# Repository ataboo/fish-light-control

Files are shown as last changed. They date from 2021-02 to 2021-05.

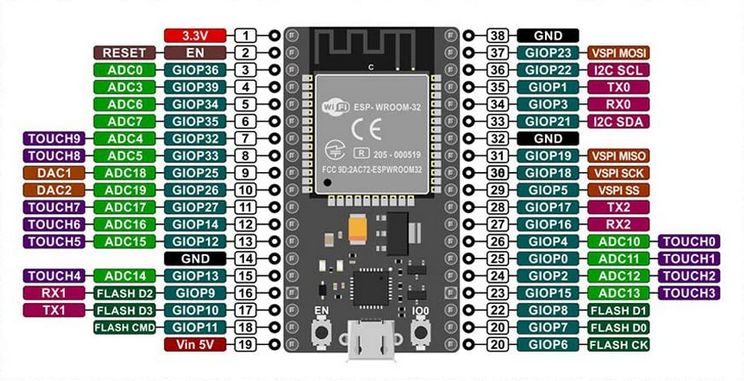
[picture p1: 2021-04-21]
eagle/DevkitPinout.PNG

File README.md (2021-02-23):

# Fish Light Control

ESP32 controlling the brightness of addressable LEDS depending on the time of day.  Intended as lighting for a fish tank.

## Hardware

- ESP32 dev kit
- WS2812B light strip
- SN74HCT04N HEX inverter

SN74HCT04N shifts the signal level from 3.3v to 5v by inverting twice.

## Install

Setup typical ESP-IDF environment (tested on IDF 4.2).  Menu options for `ESP-Fish-Light`.  Setup SSID/PW for time synchronizations. Set sunrise/set start/end in format `hhmm`.  Set timezone according to POSIX rules.  Set color of full brightness.

## Behaviour

Device will sleep until the start of sunrise or sunset, then wake every minute to update the color during the transitions.  WIFI will be activated on first start as time establishment is required, then after light update if 24 hours has passed since the last update.

Blue lights mean initial loading/time sync.  Red lights mean failed initial load.

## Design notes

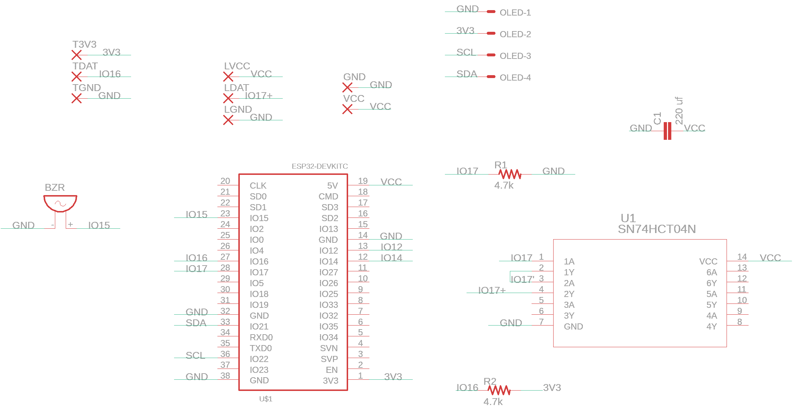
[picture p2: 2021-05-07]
eagle/Pinout_FishLightBoard_V1.1.PNG

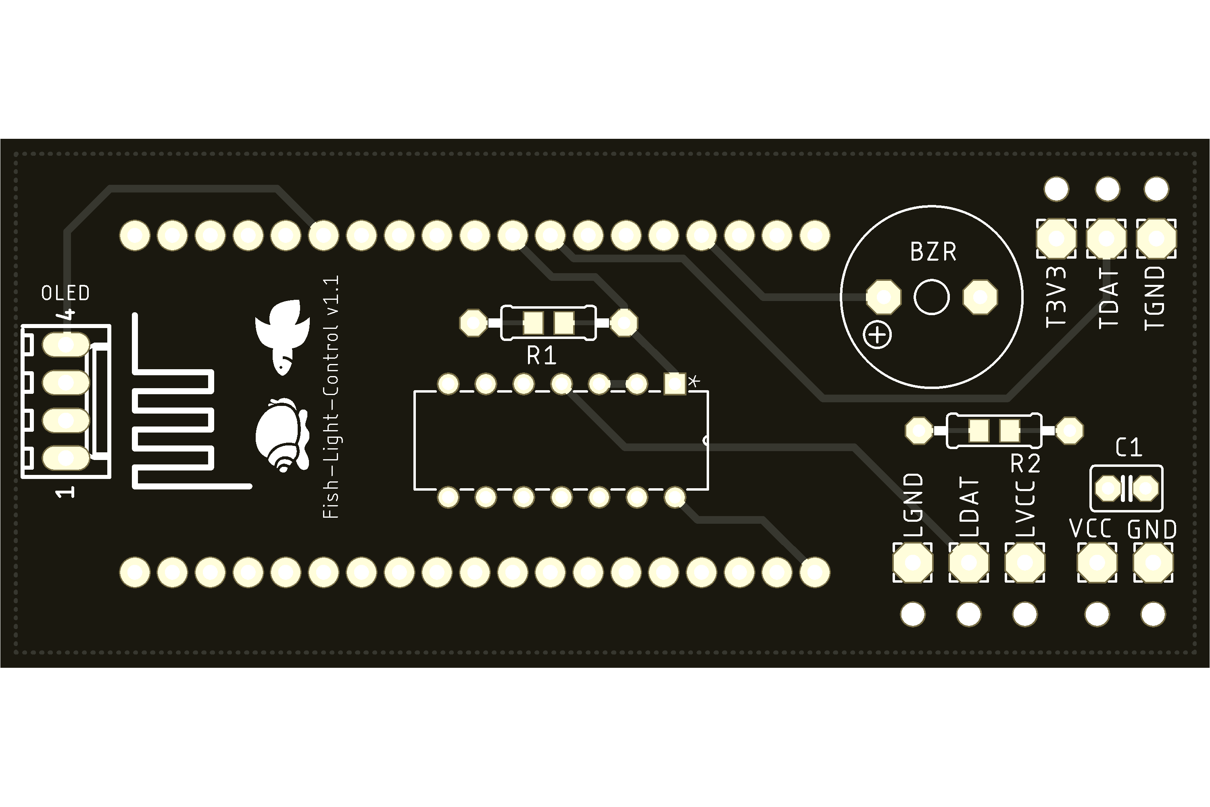
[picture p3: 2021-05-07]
eagle/ESP32FishLightBoard_v1.1.png

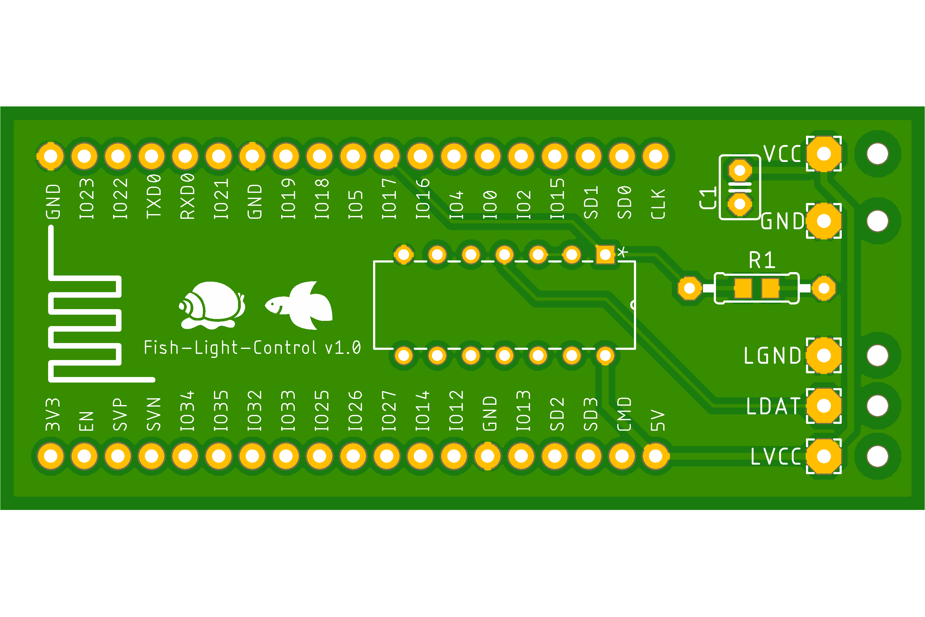
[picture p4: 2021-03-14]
eagle/ESP32FishLightBoard.png

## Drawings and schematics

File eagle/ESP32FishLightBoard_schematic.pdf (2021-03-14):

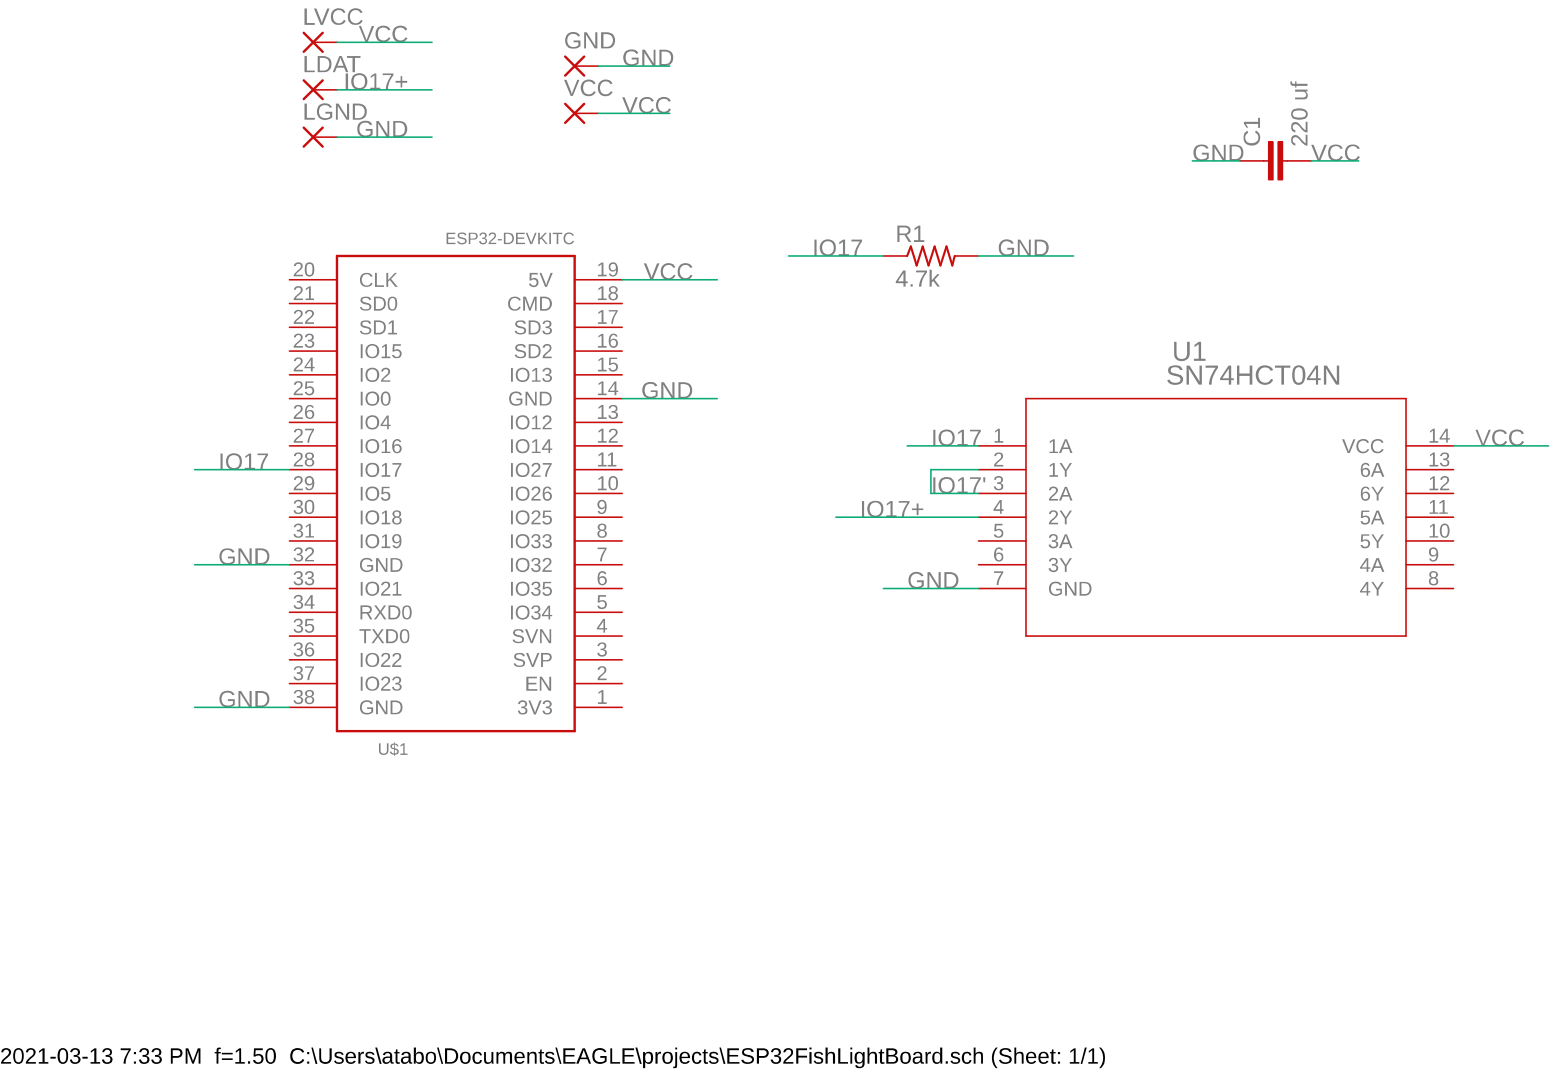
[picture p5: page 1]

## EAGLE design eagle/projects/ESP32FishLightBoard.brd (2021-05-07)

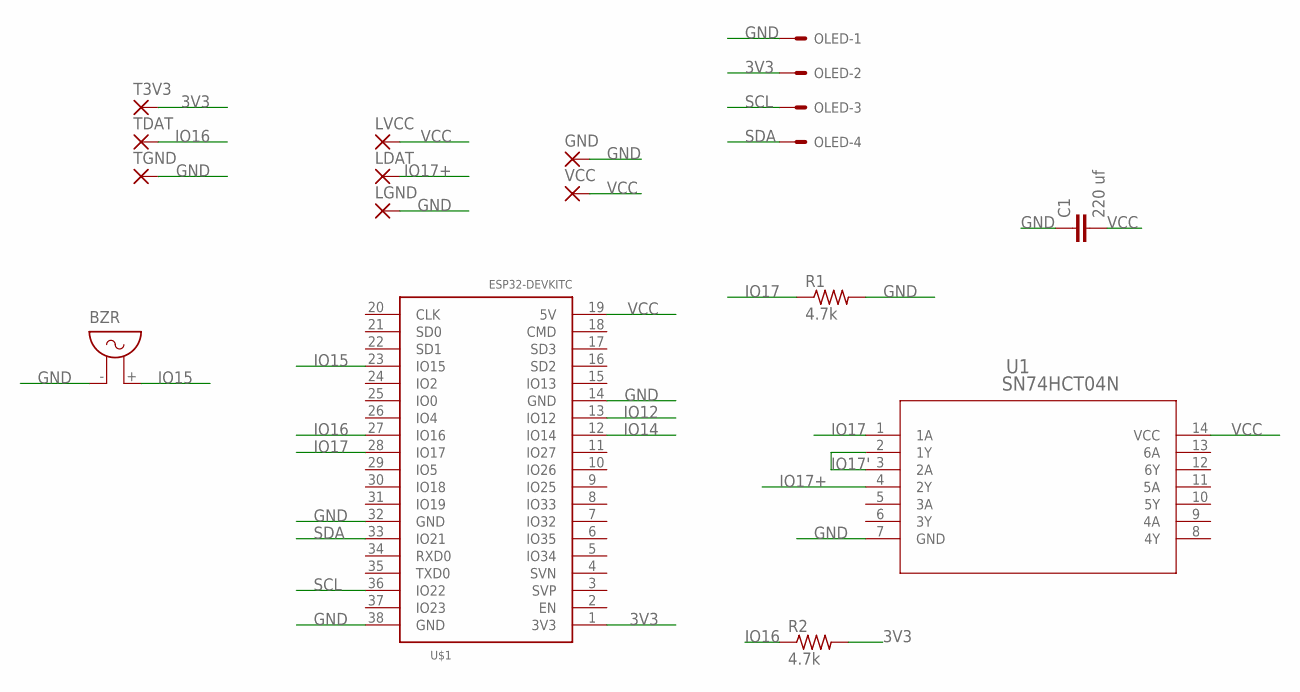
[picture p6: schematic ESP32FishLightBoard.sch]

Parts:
BZR: F/QMX
C1: 220 uf; C2.5-3
GND: WIREPAD2,54/1,0; 2,54/1,0
LDAT: WIREPAD2,54/1,0; 2,54/1,0
LGND: WIREPAD2,54/1,0; 2,54/1,0
LVCC: WIREPAD2,54/1,0; 2,54/1,0
OLED: 22-27-2041-04; 6410-04
R1, R2: 4.7k; 0805-THM
T3V3: WIREPAD2,54/1,0; 2,54/1,0
TDAT: WIREPAD2,54/1,0; 2,54/1,0
TGND: WIREPAD2,54/1,0; 2,54/1,0
U1: SN74HCT04N; N14
U$1: ESP32DEVKITC-LIGHT; ESP32-DEVKITC-LIGHT
VCC: WIREPAD2,54/1,0; 2,54/1,0

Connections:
3V3: OLED.2, R2.2, T3V3.1, U$1.1 (3V3)
GND: BZR.- (1), C1.1, GND.1, LGND.1, OLED.1, R1.2, TGND.1, U1.7 (GND), U$1.14 (GND), U$1.32 (GND), U$1.38 (GND)
IO12: U$1.13 (IO12)
IO14: U$1.12 (IO14)
IO15: BZR.+ (2), U$1.23 (IO15)
IO16: R2.1, TDAT.1, U$1.27 (IO16)
IO17: R1.1, U1.1 (1A), U$1.28 (IO17)
IO17': U1.2 (1Y), U1.3 (2A)
IO17+: LDAT.1, U1.4 (2Y)
SCL: OLED.3, U$1.36 (IO22)
SDA: OLED.4, U$1.33 (IO21)
VCC: C1.2, LVCC.1, U1.14 (VCC), U$1.19 (5V), VCC.1

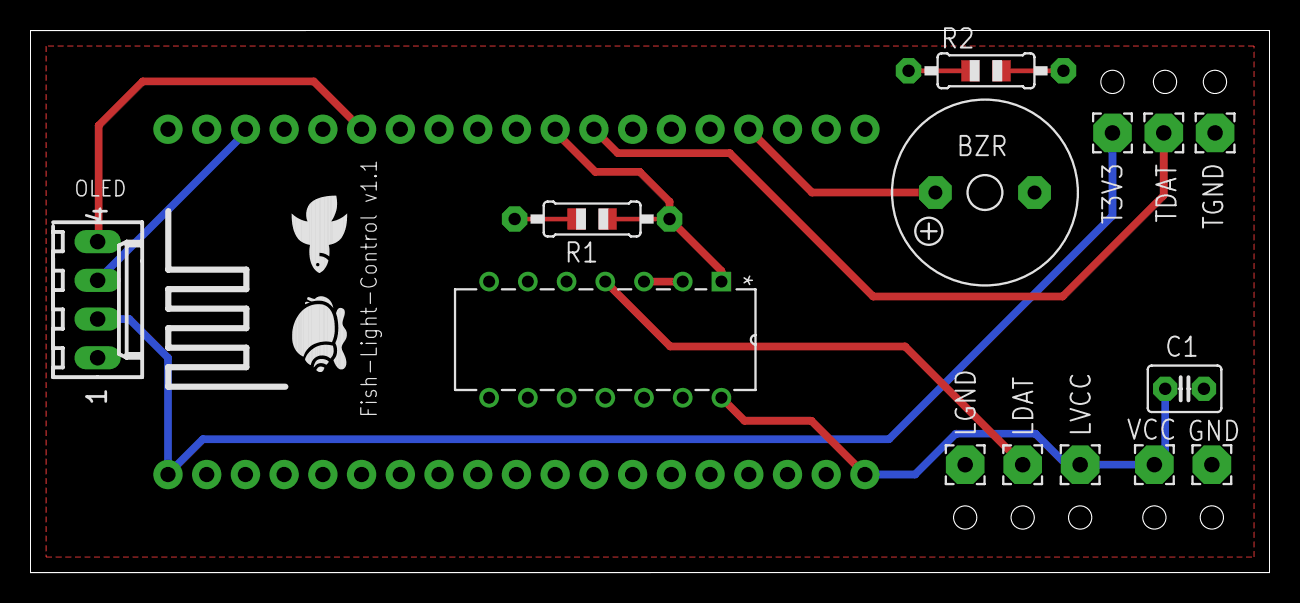
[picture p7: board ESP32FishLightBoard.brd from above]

Board: 2 copper layers, 81.3 x 35.6 mm, 15 parts (0 on the bottom side), 10 nets.

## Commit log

2021-02-25 added pull-down resistor to board
    [ESP32FishLightBoard.brd, ESP32FishLightBoard.sch]
2021-03-14 updated eagle board
    [ESP32FishLightBoard.brd, ESP32FishLightBoard.sch]
2021-04-21 updated to v1.1 PCB
    [ESP32FishLightBoard.brd, ESP32FishLightBoard.sch]
2021-05-07 Adding eagle for v1.1 board
    [ESP32FishLightBoard.brd, ESP32FishLightBoard.sch]
